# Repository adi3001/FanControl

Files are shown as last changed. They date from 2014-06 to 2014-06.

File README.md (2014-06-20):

# FanControl by CyberPlant

The a sample code for automatic speed control for the fan.
__________

# Description

Is, a compact device with a combination of some simple and useful functions.
The CyberPlant Automatic Fan Control measures temperature via the ds18b20 sensor.
the  temperature  sensor can be installed on the device or any other location
One single sensor can be connected directly to the device itself, or multiple sensors can be connected in series, for more precise ambient temperature reading. 
The CyberPlant Automatic Fan Control has offers smooth adjustments to the fan resolution speed. 
The combination of all the functions offer a precise versatile aid to controlling the temperature.

The fan motor takes its power directly from AC current running at 50Hz or 60Hz.

How does it work?
Setting up the CyberPlant Automatic Fan Control is very simple.

There are only two buttons required to set the programmable options.
With these, we can set the desired temperature values and also the Manual or Automatic Modes.

Automatic Mode.
During automatic mode if the temperature exceeds the set value, the electric charge will pulse every 2 seconds to add momentum.
If the temperature drops below the set value the fan speed will decrease until it stops. 
If the air temperature remains constant no change will occur.

This method allows the device to set the optimal speed for the fan, it prevents the temperature from exceeding the predetermined limit, reducing the total fan revolutions to the minimum possible and thereby saving on power consumption and noise levels.

On Manual Mode.
If you press the two buttons simultaneously the device will enter manual mode.
Here we can manually set the required power to the appliance and the settings are stored in non-volatile memory.
To switch back to automatic mode again just press both buttons simultaneously.

All logical parts are built on the ATmega328 microcontroller running the Arduino IDE. 
The Arduino board provides I2C Pins for connecting the device to other microcontrollers and a 6-pin to USB-TTL for easy program customisation which makes it all a very flexible and easily modifiable.to fit all your needs.
For example, maybe you would like to connect the device to the Internet this is easily done with the Arduino Internet Shield. 

or maybe you want the opposite, to heat the air in the room? It is easy! You can easily change the configuration of the device.

FanControl works with 220V AC and 110V AC at 50 Hz and 60 Hz And allows you to control the current to 4 amperes

It can display temperature in Celsius and Fahrenheit. 

FanControl is a simple and intuitive device with a great potential for modification and expansion. 
Use your imagination and a set of ready-made programs from Arduino IDE can build the automation of your dreams. 
This is an open source project. 

CyberPlant - help to people and love to plants

### Specifications

Temp sensor - DS18B20
Triac - 4A
works with 220V AC and 110V AC at 50 Hz and 60 Hz

[WWW.CYBERPLANT.INFO](http://www.cyberplant.info)

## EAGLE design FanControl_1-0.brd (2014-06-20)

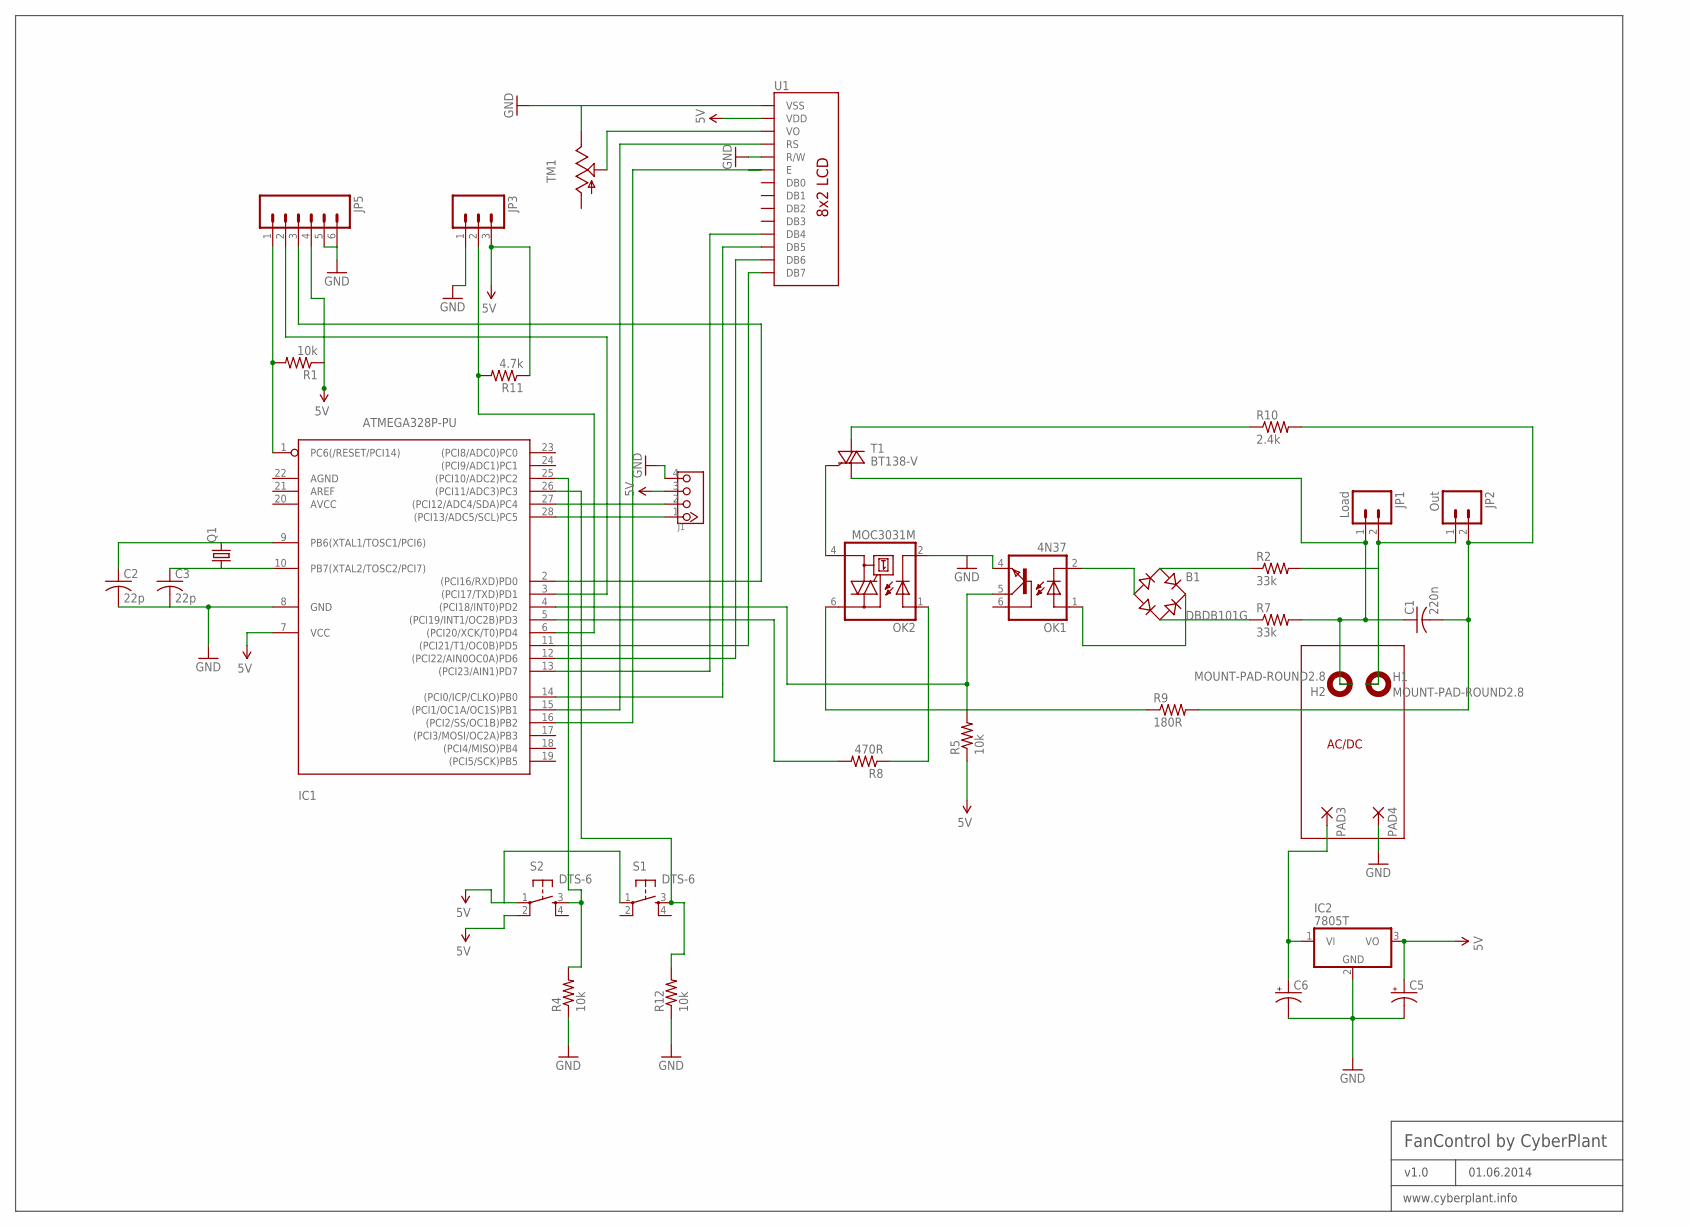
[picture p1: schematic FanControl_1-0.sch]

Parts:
B1: DBDB101G; DB
C1: 220n; C150-064X183
C2, C3: 22p; C050-025X075
C5, C6: CAP_POLPTH2; CPOL-RADIAL-10UF-25V
H1, H2: MOUNT-PAD-ROUND2.8; 2,8-PAD
IC1: ATMEGA328P-PU; DIL28-3
IC2: 7805T; TO220H
J1: TWIG-4P-2.090D; 4P-2.0-90D
JP1: Load; SCREWTERMINAL-5MM-2
JP2: Out; SCREWTERMINAL-5MM-2
JP3: M031X03_NO_SILK; 1X03_NO_SILK
JP5: M06SIP; 1X06
OK1: 4N37; DIL06
OK2: MOC3031M; DIL06
PAD3, PAD4: 1,6/0,8
Q1: CRYSTALHC49S; HC49/S
R1, R4, R5, R12: 10k; 1/6W-RES
R2, R7: 33k; AXIAL-0.6
R8: 470R; AXIAL-0.4
R9: 180R; AXIAL-0.8
R10: 2.4k; AXIAL-0.8
R11: 4.7k; AXIAL-0.4
S1, S2: DTS-6
T1: BT138-V; TO220BV
TM1: TRIM; 6MM
U1: LCD-8X2-WH0802A8X2; LCD-8X2-WH0802A

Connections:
5V: C5.1 (+), IC1.7 (VCC), IC2.3 (VO), J1.3, JP3.3, JP5.4, R1.1, R5.1, R11.P$1 (1), S1.1, S2.1, S2.2, U1.2 (VDD)
GND: C2.2, C3.2, C5.2 (-), C6.2 (-), IC1.8 (GND), IC2.2 (GND), J1.4, JP3.1, JP5.5, JP5.6, OK1.4 (EMI), OK2.2 (C), PAD4.1, R4.1, R12.1, TM1.E, U1.1 (VSS), U1.5 (R/W)
unnamed: C1.1, H2.B2,8, JP1.1, R7.P$2 (2), T1.T1 (A1)
unnamed: C1.2, JP2.2, R9.P$2 (2), R10.P$2 (2)
unnamed: H1.B2,8, JP1.2, JP2.1, R2.P$2 (2)
unnamed: B1.AC1, R2.P$1 (1)
unnamed: B1.AC2, R7.P$1 (1)
unnamed: B1.-, OK1.2 (C)
unnamed: B1.+, OK1.1 (A)
unnamed: IC1.4 ((PCI18/INT0)PD2), OK1.5 (COL), R5.2
unnamed: OK2.4 (A1), T1.G
unnamed: IC1.5 ((PCI19/INT1/OC2B)PD3), R8.P$2 (2)
unnamed: OK2.1 (A), R8.P$1 (1)
unnamed: R10.P$1 (1), T1.T2 (A2)
unnamed: OK2.6 (A2), R9.P$1 (1)
unnamed: C2.1, IC1.9 (PB6(XTAL1/TOSC1/PCI6)), Q1.2
unnamed: C3.1, IC1.10 (PB7(XTAL2/TOSC2/PCI7)), Q1.1
unnamed: IC1.6 ((PCI20/XCK/T0)PD4), JP3.2, R11.P$2 (2)
unnamed: C6.1 (+), IC2.1 (VI), PAD3.1
unnamed: TM1.S, U1.3 (VO)
unnamed: IC1.15 ((PCI1/OC1A/OC1S)PB1), U1.4 (RS)
unnamed: IC1.16 ((PCI2/SS/OC1B)PB2), U1.6 (E)
unnamed: IC1.13 ((PCI23/AIN1)PD7), U1.11 (DB4)
unnamed: IC1.14 ((PCI0/ICP/CLKO)PB0), U1.12 (DB5)
unnamed: IC1.12 ((PCI22/AIN0OC0A)PD6), U1.13 (DB6)
unnamed: IC1.11 ((PCI21/T1/OC0B)PD5), U1.14 (DB7)
unnamed: IC1.25 ((PCI10/ADC2)PC2), R4.2, S2.3
unnamed: IC1.26 ((PCI11/ADC3)PC3), R12.2, S1.3
unnamed: IC1.28 ((PCI13/ADC5/SCL)PC5), J1.1
unnamed: IC1.1 (PC6(/RESET/PCI14)), JP5.1, R1.2
unnamed: IC1.27 ((PCI12/ADC4/SDA)PC4), J1.2
unnamed: IC1.3 ((PCI17/TXD)PD1), JP5.2
unnamed: IC1.2 ((PCI16/RXD)PD0), JP5.3

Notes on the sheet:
AC/DC
FanControl by CyberPlant
v1.0
01.06.2014
www.cyberplant.info

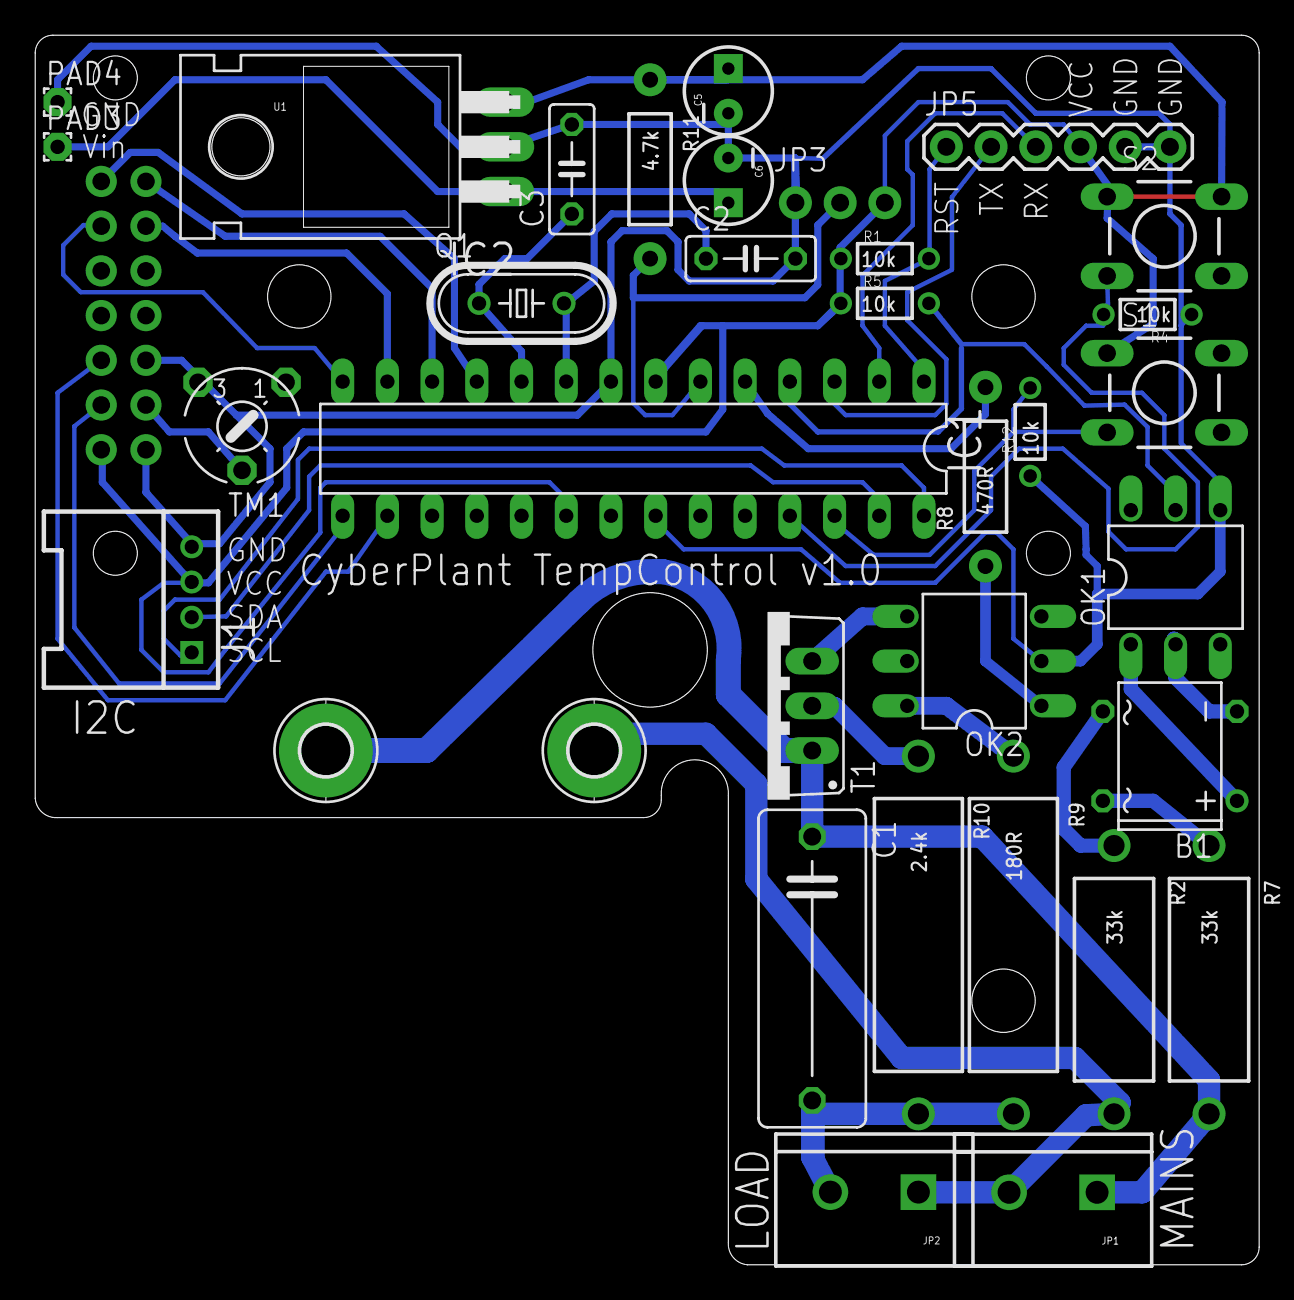
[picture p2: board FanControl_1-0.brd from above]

Board: 2 copper layers, 69.5 x 69.8 mm, 35 parts (0 on the bottom side), 33 nets.

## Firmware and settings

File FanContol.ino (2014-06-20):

// CiberPlant LLC
// http://www.cyberplant.info
// Sample code for FanControl v1.0

#include <OneWire.h>
#include <LiquidCrystal.h>
#include <EEPROMVar.h>
#include <EEPROMex.h>
#include  <TimerOne.h> 

LiquidCrystal lcd(9, 10, 7, 8, 6, 5);
OneWire  ds(4);  // линия 1-Wire будет на pin 4
int led = 13;

//int addressSetTemp = 0;
int addressR = 0;
int addressPower = addressR+sizeof(int);
int addressSetTemp = addressPower+sizeof(int);

int r = EEPROM.readInt(addressR);
int SetTemp = EEPROM.readInt(addressSetTemp);
int power = EEPROM.readInt(addressPower);

char * mode[2] = {"auto", "power"};

int m=0; 

byte upPin = A2; 
byte downPin = A3;

int flag = 0; 

long previousMillis = 0;
long interval = 2000;  // delay adjustments in minutes
//_____________________POWER___________________________

volatile int i=0;               // Variable to use as a counter
volatile boolean zero_cross=0;  // Boolean to store a "switch" to tell us if we have crossed zero
int AC_pin = 3;                // Output to Opto Triac
int dim = 0;                    // Dimming level (0-128)  0 = on, 128 = 0ff
                   // counting up or down, 1=up, -1=down

int freqStep = 78;    // This is the delay-per-brightness step in microseconds.

void setup(void) {
    lcd.begin(8, 2);
 pinMode(led, OUTPUT); 
   pinMode (upPin, INPUT);
   pinMode (downPin, INPUT);
     pinMode(AC_pin, OUTPUT);                          // Set the Triac pin as output
  attachInterrupt(0, zero_cross_detect, RISING);   // Attach an Interupt to Pin 2 (interupt 0) for Zero Cross Detection
  Timer1.initialize(freqStep);                      // Initialize TimerOne library for the freq we need
  Timer1.attachInterrupt(dim_check, freqStep);  

}
void zero_cross_detect() {    
  zero_cross = true;               // set the boolean to true to tell our dimming function that a zero cross has occured
  i=0;
  digitalWrite(AC_pin, LOW);       // turn off TRIAC (and AC)
}                                 

// Turn on the TRIAC at the appropriate time
void dim_check() {                   
  if(zero_cross == true) {              
    if(i>=dim) {                     
      digitalWrite(AC_pin, HIGH); // turn on light       
      i=0;  // reset time step counter                         
      zero_cross = false; //reset zero cross detection
    } 
    else {
      i++; // increment time step counter                     
    }                                
  }                                  
}                
void loop(void) {

 if (digitalRead(upPin)== LOW && flag==1)                           // stabilization buttons
  {
  flag=0;
  }
   if (digitalRead(downPin)== LOW && flag==1)                           // stabilization buttons
  {
  flag=0;
  }

  // Handle pressing the menu button
  if (digitalRead(upPin)== HIGH && digitalRead(downPin)== HIGH && flag==0)
  {
  r++;           // increase the variable level menu
  flag=1;
  if (r>1)       // if the level is greater than 3
  {
  r=0;           // then back to the top
  }
  EEPROM.updateInt(addressR, r);
  r = EEPROM.readInt(addressR);
}




  byte i;
  byte present = 0;
  byte type_s;
  byte data[12];
  byte addr[8];
  float celsius, fahrenheit;
  
  if ( !ds.search(addr)) {

    ds.reset_search();
    delay(100);
    return;
  }


  ds.reset();
  ds.select(addr);
  ds.write(0x44,1);         // start conversion, with parasite power on at the end
  
  delay(100);     // maybe 750ms is enough, maybe not
  // we might do a ds.depower() here, but the reset will take care of it.
  
  present = ds.reset();
  ds.select(addr);    
  ds.write(0xBE);         // Read Scratchpad

 
  for ( i = 0; i < 9; i++) {           // we need 9 bytes
  data[i] = ds.read();

 }
 

  // convert the data to actual temperature

 unsigned int raw = (data[1] << 8) | data[0];
  if (type_s) {
   raw = raw << 3; // 9 bit resolution default
    if (data[7] == 0x10) {
      // count remain gives full 12 bit resolution
      raw = (raw & 0xFFF0) + 12 - data[6];
    }
 } else 
  {
   byte cfg = (data[4] & 0x60);
    if (cfg == 0x00) raw = raw << 3;  // 9 bit resolution, 93.75 ms
    else if (cfg == 0x20) raw = raw << 2; // 10 bit res, 187.5 ms
    else if (cfg == 0x40) raw = raw << 1; // 11 bit res, 375 ms
    // default is 12 bit resolution, 750 ms conversion time
  }
 
  if (r==0)
  {
     if (digitalRead(upPin)== HIGH && flag==0)
    {
      SetTemp++;           // increase the variable level menu
  flag=1;
  if (SetTemp>60)       // if the level is greater than 3
  {
  SetTemp=60;           // then back to the top
  }
  }
      if (digitalRead(downPin)== HIGH && flag==0)
    {
      SetTemp--;           // increase the variable level menu
  flag=1;
  if (SetTemp<0)       // if the level is greater than 3
  {
  SetTemp=0;           // then back to the top
  }
  }
 if (digitalRead(upPin)== LOW && SetTemp != EEPROM.readInt(addressSetTemp))                           // stabilization buttons
  {
      EEPROM.updateInt(addressSetTemp, SetTemp);

  flag=0;
  }
  lcd.clear();
 celsius = (float)raw / 16.0;
 lcd.setCursor (0,0);
  lcd.print(mode[r]);
    lcd.setCursor (5,0);
  lcd.print(SetTemp);
 lcd.setCursor (7,0);
  lcd.print("C");
  lcd.setCursor (0,1);
  lcd.print(celsius);
  lcd.setCursor (7,1);
  lcd.print("C");
  
    unsigned long currentMillis = millis();       // for reading interval pH Delay
  if (currentMillis - previousMillis> interval)
  {  
    previousMillis = currentMillis;
  if (SetTemp>celsius)               // if the automatic mode is selected and the pH dropped
                                               // Parameter below pH Low
{

  dim++;
  if (dim>115)
  {
  dim = 115;
  }
  }
  if (SetTemp<celsius)
  {
    dim--;
    if (dim<50)
    {
    dim = 50;
    }
    }
  }
  }
  
  else if (r==1)
  {
    if (digitalRead(upPin)== HIGH && flag==0)
    {
      power++;           // increase the variable level menu
  flag=1;
  if (power>100)       // if the level is greater than 3
  {
  power=100;           // then back to the top
  }
  }
      if (digitalRead(downPin)== HIGH && flag==0)
    {
      power--;           // increase the variable level menu
  flag=1;
  if (power<0)       // if the level is greater than 3
  {
  power=0;           // then back to the top
  }
  }
 if (digitalRead(upPin)== LOW && power != EEPROM.readInt(addressPower))                           // stabilization buttons
  {
      EEPROM.updateInt(addressPower, power);

  flag=0;
  }
  
  dim = map(power, 0, 100, 115, 50);
  
  lcd.clear();
 celsius = (float)raw / 16.0;
 lcd.setCursor (0,0);
  lcd.print(mode[r]);
  lcd.setCursor (5,0);
  lcd.print(power);
  if (power<100)
  {
 lcd.setCursor (7,0);
  lcd.print("%");
  }
  lcd.setCursor (0,1);
  lcd.print(celsius);
  lcd.setCursor (7,1);
  lcd.print("C");

  }

}

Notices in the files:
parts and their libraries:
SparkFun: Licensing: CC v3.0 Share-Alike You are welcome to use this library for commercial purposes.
